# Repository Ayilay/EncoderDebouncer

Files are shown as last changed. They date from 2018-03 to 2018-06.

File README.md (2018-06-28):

# Encoder Debouncer
An simple PCB that takes a rotary encoder and debounces one of the pins

<p float="left">
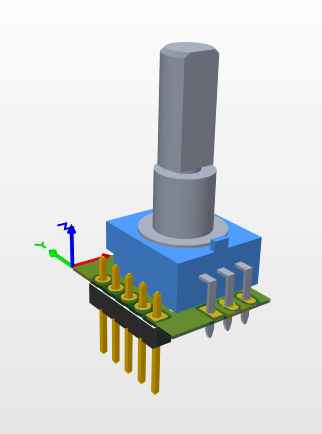
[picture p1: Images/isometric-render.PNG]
    
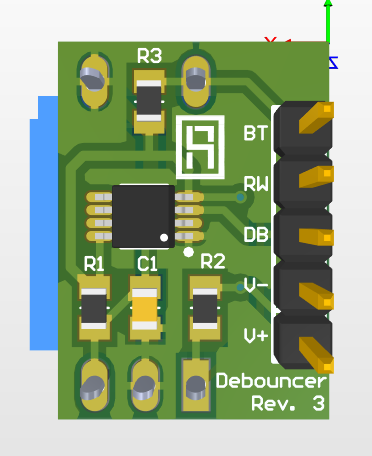
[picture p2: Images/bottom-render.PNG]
    
</p>

## What is an encoder?
A rotary encoder is a rotary device that can spin indefinitely. You might have encountered them before in a car that has a digital volume knob. They're pretty nice to use in projects as menu knobs, but using them isn't entirely straightforward. There are several great tutorials on YouTube, but all of them mention a large issue with them: bounce

## What is a debouncer?
If you've ever used push-buttons or rotary encoders with Arduino, chances are you've encountered the term "bounce" before. If not, mechanical bounce is simply a side effect of all mechanical switches. Say you have a push-button, and pushing it causes the switch contacts to connect. In a perfect world, that happens cleanly, but in the real world, the contacts will "bounce" back and forth between connected and disconnected until they eventually stabilize. Sometimes this bounce isn't a huge deal, but if you're working with Interrupts on microcontrollers that need a clean transition as an input, then removing this bounce is critical. A debouncer circuit does just that.

To visualize bounce, look at the illustration below under the _Principle of Operation (software)_ section.

There are multiple ways to remove bounce, either fully software, hardware, or both. Software is easier to implement and essentially free, but can be less reliable than hardware. Hardware requires you to buy components and assemble a debouncer circuit, but can be more reliable and leads to cleaner code.

## Inspiration for this project
As a hobbyist, I use Arduino frequently to prototype projects, and I've had to use Rotary Encoders from time to time. Anyone who's used a Rotary Encoder can vouch for what a pain they are to use with Arduino's hardware interrupts, because the mechanical nature of the encoder has bounce that needs to be filtered.

I've found software debouncing to be very frustrating and unpredictable, so I wanted to make a hardware debouncer that was easy to use. My solution was this PCB, a breadboard-friendly circuit board that is ready to use as soon as all the components are soldered on it. From there it can connect directly to an Arduino or other MCU without additional components. The PCB nature of the project also makes it very easy to print multiple pieces that behave identically.

## Debouncer Principle of Operation (hardware)
The Rotary Encoder has 2 signal pins. One of those pins is fed into an RC circuit that absorbs the bounce, but turns the digital signal into a slow-rising curve. This is fed into an Inverting Schmitt Trigger, which offers hysteresis and turns the rising voltage curve into a clean fast-rising digital signal.

I didn't have any Schmitt triggers laying around, and I didn't want to buy some just for this circuit, so I used a common 555 IC as an Inverting Schmitt trigger. It works quite well for this purpose, and I have plenty of them laying around since they are so versatile.

This circuit is heavily based on Jeremy Blum's [Arduino Tutorial #10 on Interrupts and Hardware Debouncing](https://youtu.be/CRJUdf5TTQQ), it is quite excellent. Look at it for more details on how this circuit works in principle.

To debounce a single signal, I used a single resistor, a single capacitor, and a 555 IC. To lower the component count, I only debounced one of the 2 signals, which is good enough because we only need one signal to feed into an interrupt pin.

## Debouncer Principle of Operation (software)
If you've worked with encoders before, you might be familiar with the below diagram of the 2 signal pins
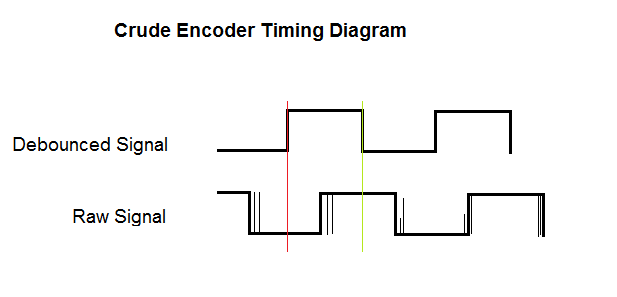
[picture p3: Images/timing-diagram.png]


You can see how the raw signal has some random bounce, but it stabilizes _before_ the important transitions in the debounced signal (the red transition and green transition).

This assumption is **critical**, and allows us to use a single interrupt, the debounced signal. Choosing a RISING or FALLING edge to trigger the interrupt makes no difference, but once the interrupt is triggered, we only need to check the state of the raw signal to determine which direction we moved in. 

Let's say for example we choose a RISING edge as our interrupt trigger, and let's assume that in the diagram, going to the right is clockwise. If we are turning clockwise, the rising edge will be the one indicated by the red line in the diagram, and we can see that the raw signal is LOW. If we are going counter-clockwise, the rising edge of the debounced signal is now the green vertical line, and we can see the raw signal is now HIGH.

Below is some example code that applies this principle in practice.

## Example code for Arduino Uno
```
#define ENC_DEB 2  // Debounced Encoder signal, feeds into interrupt 0 on Uno
#define ENC_RAW 7  // Non-Debounced Encoder signal, feeds into any pin

// A counter variable that is incremented/decremented
// whenever the encoder is rotated. Initial value is arbitrary
int counter = 300;

void setup() {
    pinMode(ENC_DEB, INPUT);
    pinMode(ENC_RAW, INPUT);

    // Execute the encoderISR function on a RISING edge
    attachInterrupt(digitalPintToInterrupt(ENC_DEB), encoderISR, RISING);

    Serial.begin(9600);
}

void encoderISR() {
    // If the counter variable is incrementing/decrementing in the opposite direction,
    // flip the increment/decrement below
    if (digitalRead(ENC_RAW))
        counter ++;
    else
        counter --;

    // Print the value of the counter every time it changes
    Serial.println(counter);
}

void loop() {
    // Nothing necessary here for interrupt
}
```

## Schematic
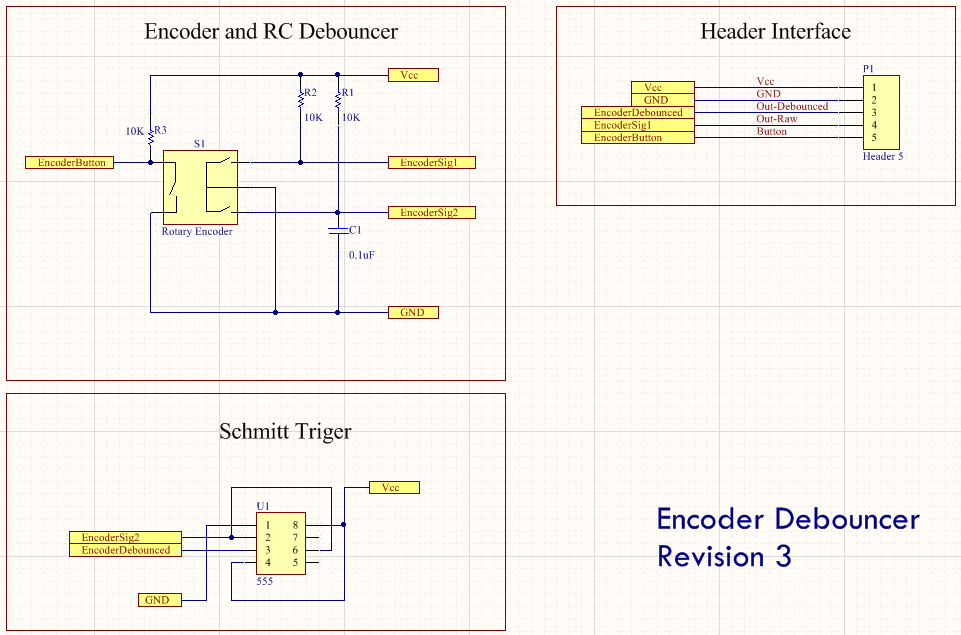
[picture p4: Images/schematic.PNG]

You can build this schematic on a breadboard and test it. I tried to use parts that are common to most electronics labs.

## Creating a PCB
This Schematic/PCB was created using Altium Designer, but I expect that many people do not have access to the specific software. Therefore, I have included the Gerber files in this repository, which you can view yourself or send to a PCB Manufacturing facility. Make sure your fabrication house can accomodate for the specifications of the board. The specs of the PCB are the following:

Attribute | Value
--- | ---
Min. Hole Size | 15 mil
Min Silkscreen Width | 5 mil
Min Trace Width | 15 mil
Board Dimensions | 535 mil x 745 mil

## Components BOM
Quantity | Part | Package | DigiKey Part Number
-------- | ---- | ------- | -------------------
1 | 555 IC | 8-VSSOP | [296-42639-1-ND](https://www.digikey.com/product-detail/en/texas-instruments/LM555CMMX-NOPB/296-42639-1-ND/5455904)
3 | RES, 10K | SMD 0805 | [311-10KARCT-ND](https://www.digikey.com/product-detail/en/yageo/RC0805JR-0710KL/311-10KARCT-ND/731188)
1 | CAP, 0.1uF | SMD 0805 | [311-3562-1-ND](https://www.digikey.com/product-detail/en/yageo/CC0805JRX7R8BB104/311-3562-1-ND/7648489)
1 | Rotary Encoder | | (see note 1 below)
1 | 5-pin Male Header | 0.1" (2.54 mm) Pitch |

(note 1) The footprint for the encoder has 5 holes, 3 on one side and 2 on the other. The holes are 0.1" apart, and the 2 rows of holes are 0.6" apart. Most cheap rotary encoders have very similar footprints. Worst case you will have to bend the pins a little bit to make them fit nicely

## Additional Hardware Insights
You might notice that Capacitor C1 charges through R1, but discharges relatively instantaneously because it shorts to GND. As such, the RC-Debouncing technically only happens while the capacitor is charging, (signal is RISING), but that feeds into the Inverting Schmitt Trigger, so the signal is only guaranteed to be properly debounced on a FALLING edge. For maximum reliability, choose the FALLING edge as the interrupt trigger in the software

If you build this circuit, do beware: The resistor/capacitor values I chose are dependent on the specific encoders I had, and were calculated to filter out bounce that lasted no longer than 1 ms. While building my debouncer, I stumbled upon this [wonderful guide to debouncing](http://www.eng.utah.edu/~cs5780/debouncing.pdf). It has great explanations, and some humor sprinkled here and there, I strongly recommend reading it to gain a better understanding of debouncing. I used it as a reference for calculating the resistor/capacitor values

It is most likely that your encoder will have similar bounce, no more than 1 ms in duration, so the values I used are most likely compatible. But do feel free to change them as you see fit.

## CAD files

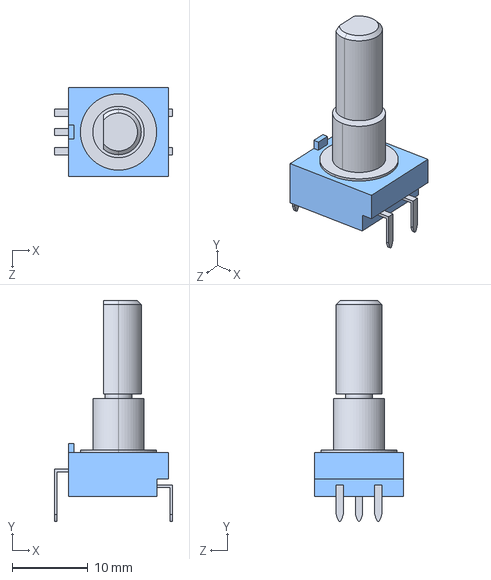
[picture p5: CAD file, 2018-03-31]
3D Bodies/RotaryEncoder.STEP
15.6 x 29.1 x 11.7 mm

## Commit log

2018-03-31 Pushed rev2 (rev1 is not present)
    [EncoderDebouncer.PcbDoc, EncoderDebouncer.PrjPcb, EncoderDebouncer.SchDoc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]
2018-03-31 Fixed error in schematic
2018-03-31 Fixed schematic error (to become rev3), TODO PCB
    [EncoderDebouncer.SchDoc]
2018-04-01 Added Rev3 PCB and Gerbers
    [EncoderDebouncer.PcbDoc, EncoderDebouncer.PrjPcb, EncoderDebouncerComponents.PcbLib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]
2018-04-01 Updated schematic to rev3
    [EncoderDebouncer.SchDoc]
